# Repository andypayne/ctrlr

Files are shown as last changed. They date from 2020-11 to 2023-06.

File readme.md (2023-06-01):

# CTRLR MIDI Controller

A programmable MIDI Controller

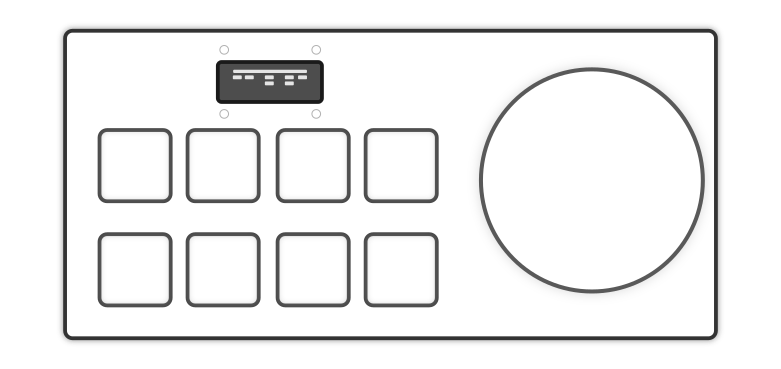
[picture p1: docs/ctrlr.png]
CTRLR


## Hardware

- [Teensy 4.0](https://www.pjrc.com/store/teensy40.html)
- [Adafruit SSD1306 128x32 display](https://www.adafruit.com/product/661)
- 8 pushbuttons (from [Anchor Electronics](https://anchor-electronics.com/))
- A rotary encoder
- 3D-printed enclosure, buttons caps, and rotary wheel

### Enclosure

The [enclosure](/enclosure) was designed with [Solvespace](https://solvespace.com/), a parametric 3D CAD tool. The button pads and dial were designed with [OpenSCAD](http://www.openscad.org/).

#### Top

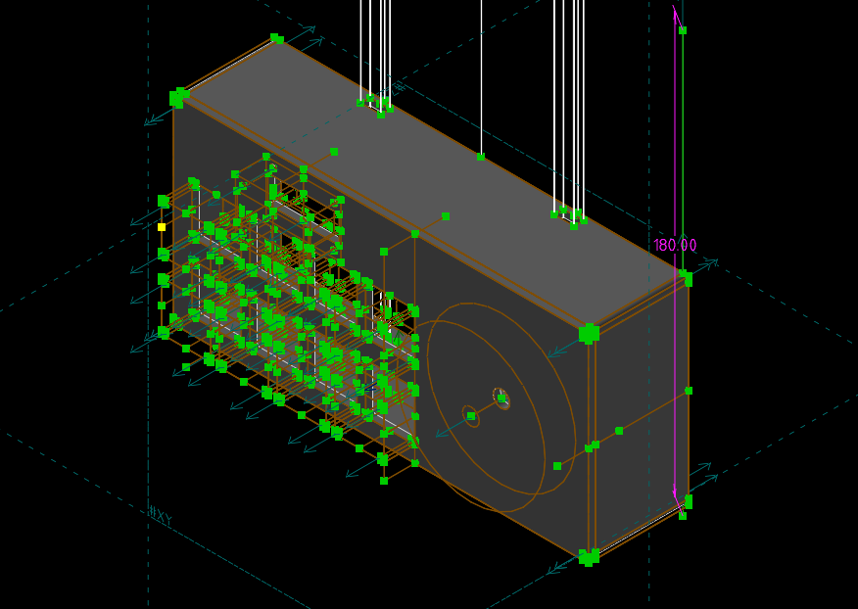
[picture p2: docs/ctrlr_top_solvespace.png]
CTRLR Enclosure Top


#### Bottom

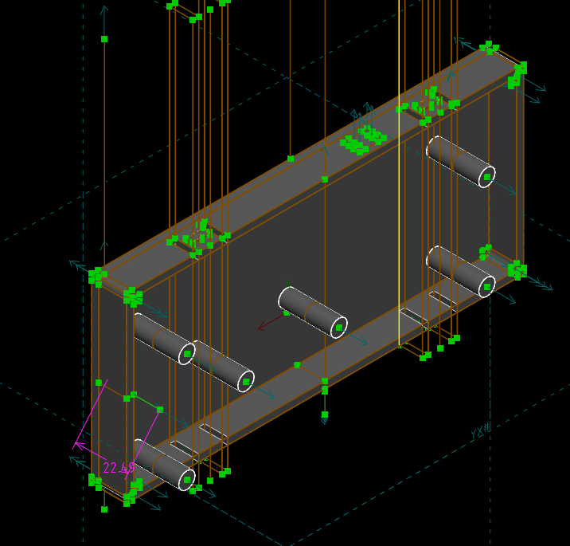
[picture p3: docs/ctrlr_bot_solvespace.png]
CTRLR Enclosure Bottom


## Installation with Arduino

### Arduino

Install [Arduino](https://www.arduino.cc/en/software) 2.0+.

### Teensyduino

Follow [these instructions](https://www.pjrc.com/teensy/td_download.html) to install the Teensyduino add-on. ([board manager url](https://www.pjrc.com/teensy/package_teensy_index.json))

Then to use the Teensy 4.0 board, in the Arduino menu select `Tools -> Board -> Teensy -> Teensy 4.0`.

### Adafruit libraries

To use the SSD1306 display, these libraries need to be installed in Arduino. For newer versions, just search for and install the display type in the Arduino library manager (`"Adafruit SSD1306"` for this project), and the required dependencies (notably Adafruit GFX Library & Adafruit BusIO Library) will be installed with it.

- [Adafruit GFX Graphics Library](https://learn.adafruit.com/adafruit-gfx-graphics-library/overview)
- [Adafruit SSD1306](https://github.com/adafruit/Adafruit_SSD1306)

### Project Dependencies

Clone these repositories:

- [buttoner](https://github.com/andypayne/buttoner)
- [midi_defs](https://github.com/andypayne/midi_defs)

### USB MIDI

To enable [MIDI device](https://www.pjrc.com/teensy/td_midi.html) support for the Teensy, select `Tools -> USB Type -> MIDI` in the Arduino menu. Then the project should build successfully. To upload to a board, select the appropriate port.

## Pure Data integration

Objects for [Pure Data](https://puredata.info/) are located in [/PureData](/PureData).

### ctrlr.pd

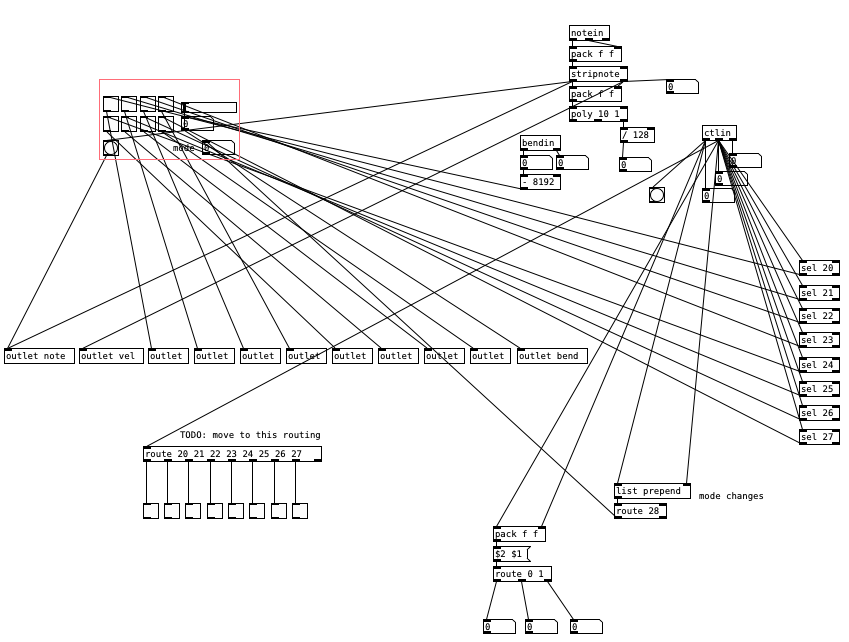
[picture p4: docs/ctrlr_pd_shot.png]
ctrlr.pd


### ctrlr_test.pd

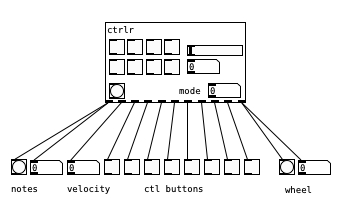
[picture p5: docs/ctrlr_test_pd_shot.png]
ctrlr_test.pd


## Operation Modes

### 16-Step Sequencer

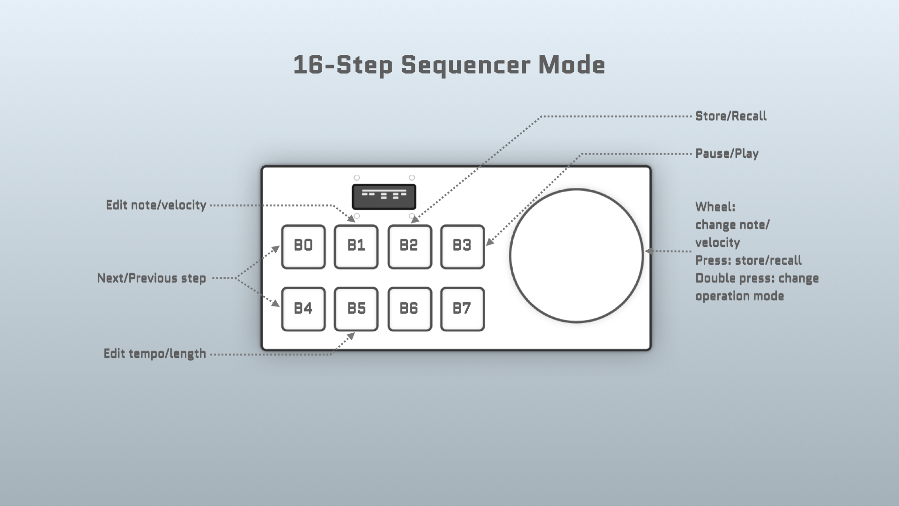
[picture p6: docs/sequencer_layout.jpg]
sequencer mode


## Issues

### Enclosure

The enclosure had several issues, most of which would be fixed in a second revision. I haven't done this yet, partially due to the difficulty and cost of printing another revision.

- _Material_ - The 3D-printed material is a bit too brittle for this application.
- _Height_ - The enclosure is unnecessarily tall, due to my poor planning. I think it gives the device a clunky 70s feel.
- _Support columns_ - I didn't properly attach these to the base in Solvespace, so most of them separated after printing.
- _Button travel_ - The button switches I used have too much travel for this application. I was determined to use these particular switches for some inexplicable reason.
- _Access to reset_ - The access to the reset button requires disassembling the enclosure, which is not ideal when making mistakes while developing code for the device.
- _Piece fit_ - I made an error in Solvespace when designing the fit mechanism for the top and bottom pieces, so I had to use screws to attach the pieces. This makes the device more fragile.
- _USB port_ - I didn't account for the USB port in my enclosure design, so I had to drill/route a hole for it.

### Screen

- _Size_ - The screen size is too small. The positive benefit of this is that it provided a constraint that required some creativity to overcome with some of the modes. It was an interesting challenge to fit the right details on the available screen real estate.
- _Asymmetry_ - I didn't pay close attention to the screen asymmetry when designing the enclosure cutout for it. The screen sits to one side of the cutout.
- _Screen fit_ - I mis-measured the mounting layout for the screen, so the resulting mount on the enclosure is the wrong size, and so the mounted screen causes the enclosure to bow out a little.
- _Screen connectors_ - I didn't properly account for the screen's header pins and connectors header pin connectors when laying out the enclosure, so I had to refit them, and cut out a section of my stripboard to accommodate.

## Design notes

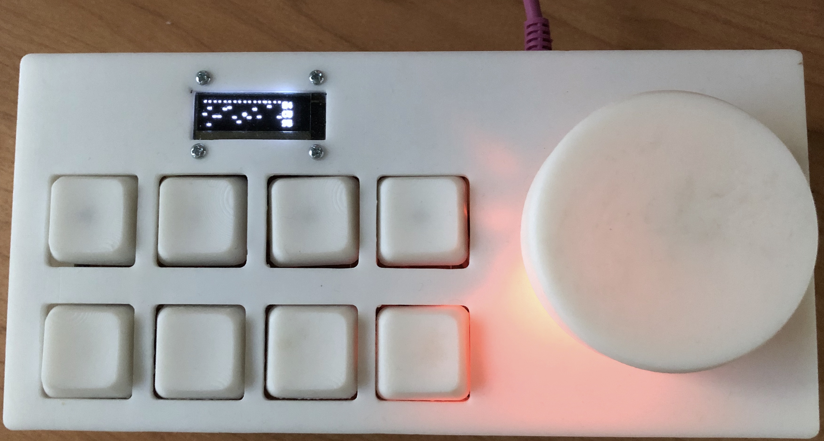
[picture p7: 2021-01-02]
docs/CTRLR_overhead_shot.jpg

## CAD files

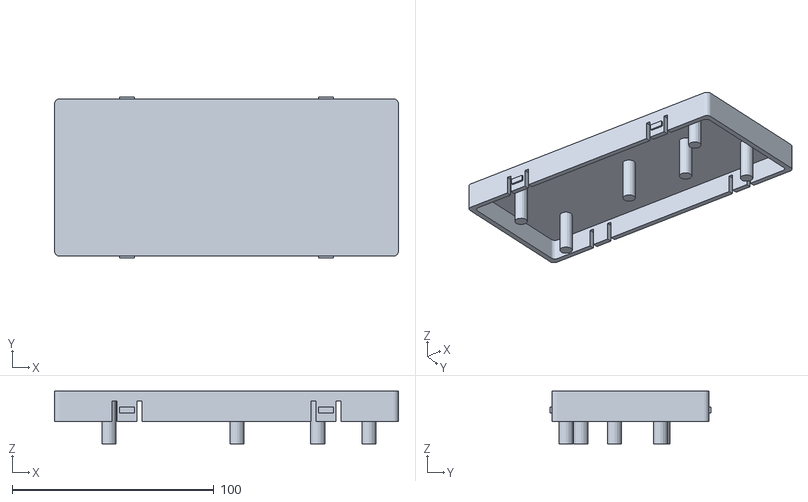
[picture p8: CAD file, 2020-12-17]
enclosure/ctrlr_enclosure_bot.stl
170.5 x 80.0 x 26.2

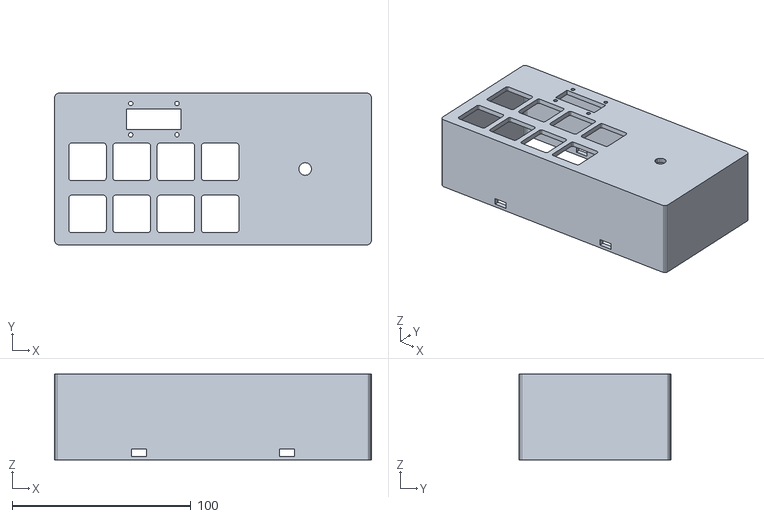
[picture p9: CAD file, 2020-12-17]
enclosure/ctrlr_enclosure_top.stl
177.5 x 85.0 x 48.0

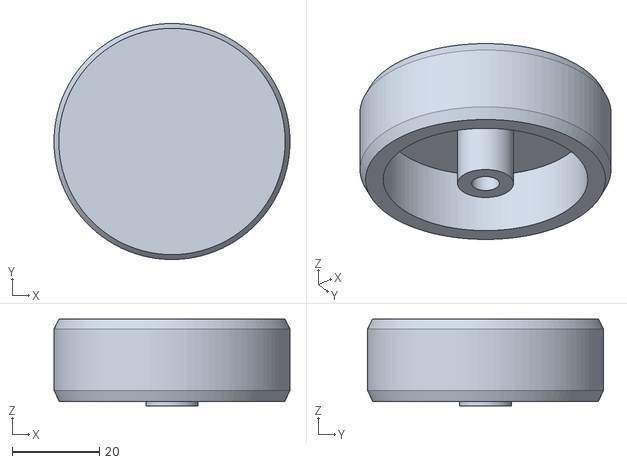
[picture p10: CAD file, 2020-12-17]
enclosure/ctrlr_enclosure_knob.stl
54.0 x 54.0 x 19.8

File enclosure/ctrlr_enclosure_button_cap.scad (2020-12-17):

$fn = 150;

cross_bar_thickness     = 1.13;
cross_height            = 4.52;
// The cross bar is off centered, so I'm making both bar dimensions equal to
// the longest bar to minimize fit issues.
//cross_width             = 3.76;
cross_width             = 4.52;
cross_z_height          = 5.6 + 0.2;
button_base_width       = 15;
button_base_length      = 15;
button_height           = 8;
button_offset           = 3;
button_height_scale     = 0.75;
button_top_neg_radius   = 40;
button_neg_z_pos        = button_height + 0.968 * button_top_neg_radius;

module button_crossbar() {
    color("purple")
    translate([-0.5 * cross_width, -0.5 * cross_bar_thickness, 0])
    cube([cross_width, cross_bar_thickness, cross_z_height]);

    translate([-0.5 * cross_bar_thickness, -0.5 * cross_height, 0])
    cube([cross_bar_thickness, cross_height, cross_z_height]);
}

module button_body() {
color("blue")
translate([0, 0, 0.1])
linear_extrude(height = button_height, center = false, convexity = 20, scale=button_height_scale)
translate([
    -0.5 * button_base_length,
    -0.5 * button_base_width,
    0.5 * button_height])
offset(r=button_offset)
square(size=[button_base_length, button_base_width]);
}

module button_top_neg() {
    translate([0, 0, button_neg_z_pos])
    sphere(r=button_top_neg_radius);
}

translate([21, 0, 0])
difference() {
    button_body();
    button_crossbar();
    button_top_neg();
}

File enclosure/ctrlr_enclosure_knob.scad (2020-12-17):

$fn = 100;

// All in mm

threaded_shaft_diam    = 7.1;  // Not used, too low
threadless_shaft_diam  = 6.0;
notch_pos_thickness    = 4.8;
notched_shaft_height   = 10.5;
notchless_shaft_height = 3.3;
top_thickness          = 5.0;
outer_cyl_height       = notched_shaft_height + notchless_shaft_height + top_thickness;
outer_cyl_diam         = 54.0;
shaft_hole_diam        = 6.0;
notch_neg_width        = threadless_shaft_diam - notch_pos_thickness;

neg_inner_cyl_height = outer_cyl_height;
neg_inner_cyl_diam   = outer_cyl_diam - 10.0;
inner_post_overhang  = 1.0;
inner_post_height    = outer_cyl_height + inner_post_overhang;
inner_post_diam      = 12.0;
shaft_hole_height    = inner_post_height;

// Notch in the shaft negative
color("red")
translate([0.5 * threadless_shaft_diam - notch_neg_width, -0.5 * threadless_shaft_diam, notchless_shaft_height])
cube([notch_neg_width, threadless_shaft_diam, notched_shaft_height]);

intersection() {
    intersection() {
        // Negative cone for chamfer top
        translate([0, 0, -50]) cylinder(h=120, d1=120, d2=1);
        difference() {
            cylinder(h=outer_cyl_height, d=outer_cyl_diam);
            translate([0, 0, -top_thickness])
                cylinder(h=neg_inner_cyl_height, d=neg_inner_cyl_diam);
        }
    }

    // Negative cone for chamfer bottom
    rotate([180, 0, 0]) translate([0, 0, -69]) cylinder(h=120, d1=120, d2=1);
}


difference() {
    translate([0, 0, -inner_post_overhang])
        cylinder(h=inner_post_height, d=inner_post_diam);
    translate([0, 0, -inner_post_overhang - 3.0])
        cylinder(h=shaft_hole_height, d=shaft_hole_diam);
}

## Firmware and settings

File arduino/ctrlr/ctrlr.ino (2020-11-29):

#include "ctrlr.h"

//
// Set Tools --> USB Type --> MIDI
//

#define MIDI_CHANNEL 1

#define IN0_BTN     21
#define IN1_BTN     19
#define IN2_BTN     17
#define IN3_BTN     15
#define IN4_BTN     20
#define IN5_BTN     18
#define IN6_BTN     16
#define IN7_BTN     22
#define IN_RENC_SW  7
#define IN_RENC_DT  5
#define IN_RENC_CLK 6

Ctrlr ctrlr(
  MIDI_CHANNEL,
  IN0_BTN,
  IN1_BTN,
  IN2_BTN,
  IN3_BTN,
  IN4_BTN,
  IN5_BTN,
  IN6_BTN,
  IN7_BTN,
  IN_RENC_SW,
  IN_RENC_DT,
  IN_RENC_CLK
);

void setup() {
  Serial.begin(9600);
  randomSeed(analogRead(0));
  ctrlr.setup();
}

void loop() {
  ctrlr.update();
}

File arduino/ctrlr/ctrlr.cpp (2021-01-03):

#include "ctrlr.h"

Ctrlr::Ctrlr(
  int midiChannel,
  int in0Pin,
  int in1Pin,
  int in2Pin,
  int in3Pin,
  int in4Pin,
  int in5Pin,
  int in6Pin,
  int in7Pin,
  int inRencSwitch,
  int inRencDT,
  int inRencCLK) :
    _modeChanging(false),
    _modeSel(mnote),
    _sw_millis(SW_MILLIS),
    _rencBtnr(HIGH, LOW, HIGH, SW_MILLIS, SW_DBL_MILLIS),
    _b0Btnr(HIGH, LOW, HIGH, SW_MILLIS, SW_DBL_MILLIS),
    _b1Btnr(HIGH, LOW, HIGH, SW_MILLIS, SW_DBL_MILLIS),
    _b2Btnr(HIGH, LOW, HIGH, SW_MILLIS, SW_DBL_MILLIS),
    _b3Btnr(HIGH, LOW, HIGH, SW_MILLIS, SW_DBL_MILLIS),
    _b4Btnr(HIGH, LOW, HIGH, SW_MILLIS, SW_DBL_MILLIS),
    _b5Btnr(HIGH, LOW, HIGH, SW_MILLIS, SW_DBL_MILLIS),
    _b6Btnr(HIGH, LOW, HIGH, SW_MILLIS, SW_DBL_MILLIS),
    _b7Btnr(HIGH, LOW, HIGH, SW_MILLIS, SW_DBL_MILLIS),
    _bb0({ defBtnMode, 60, maj_7(60), 20, MidiDefs::MIDI_HIGH, 0, Metro(BPM_TO_MILLIS(DEF_REP_BPM)) }),  // Cmaj
    _bb1({ defBtnMode, 61, min_7(62), 21, MidiDefs::MIDI_HIGH, 0, Metro(BPM_TO_MILLIS(DEF_REP_BPM)) }),  // Dmin
    _bb2({ defBtnMode, 62, min_7(64), 22, MidiDefs::MIDI_HIGH, 0, Metro(BPM_TO_MILLIS(DEF_REP_BPM)) }),  // Emin
    _bb3({ defBtnMode, 63, maj_7(65), 23, MidiDefs::MIDI_HIGH, 0, Metro(BPM_TO_MILLIS(DEF_REP_BPM)) }),  // Fmaj
    _bb4({ defBtnMode, 64, dom_7(67), 24, MidiDefs::MIDI_HIGH, 0, Metro(BPM_TO_MILLIS(DEF_REP_BPM)) }),  // Gmaj
    _bb5({ defBtnMode, 65, min_7(69), 25, MidiDefs::MIDI_HIGH, 0, Metro(BPM_TO_MILLIS(DEF_REP_BPM)) }),  // Amin
    _bb6({ defBtnMode, 66, dim_7(71), 26, MidiDefs::MIDI_HIGH, 0, Metro(BPM_TO_MILLIS(DEF_REP_BPM)) }),  // Bmin7b5
    _bb7({ defBtnMode, 67, maj_7(72), 27, MidiDefs::MIDI_HIGH, 0, Metro(BPM_TO_MILLIS(DEF_REP_BPM)) }),  // Cmaj
    _btn0_tog(HIGH),
    _btn1_tog(HIGH),
    _btn2_tog(HIGH),
    _btn3_tog(HIGH),
    _btn4_tog(HIGH),
    _btn5_tog(HIGH),
    _btn6_tog(HIGH),
    _btn7_tog(HIGH),
    _renc(inRencDT, inRencCLK),
    _display(
      SCREEN_WIDTH,
      SCREEN_HEIGHT,
      OLED_MOSI,
      OLED_CLK,
      OLED_DC,
      OLED_RESET,
      OLED_CS),
    _metroBpm(METRO_BPM),
    _metro(BPM_TO_MILLIS(METRO_BPM)),
    _seqNote(0),
    _delayOn(false),
    _chordsOn(false),
    //_seqSteps{ {0, 0}, {0, 0}, {0, 0}, {0, 0}, {0, 0}, {0, 0}, {0, 0}, {0, 0}, {0, 0}, {0, 0}, {0, 0}, {0, 0}, {0, 0}, {0, 0}, {0, 0}, {0, 0} },
    //_seqSteps{ {60, 64}, {64, 80}, {62, 0}, {60, 10}, {66, 80}, {64, 0}, {66, 10}, {62, 80}, {60, 0}, {64, 10}, {68, 80}, {62, 0}, {62, 10}, {64, 0}, {60, 64}, {70, 90} },
    //_seqSteps{ {60, 0}, {60, 0}, {60, 0}, {60, 0}, {60, 0}, {60, 0}, {60, 0}, {60, 0}, {60, 0}, {60, 0}, {60, 0}, {60, 0}, {60, 0}, {60, 0}, {60, 0}, {60, 0} },
    _seqSteps{ {60, 95}, {60, 95}, {60, 95}, {60, 95}, {60, 95}, {60, 95}, {60, 95}, {60, 95}, {60, 95}, {60, 95}, {60, 95}, {60, 95}, {60, 95}, {60, 95}, {60, 95}, {60, 95} },
    _seqEditStep(0),
    _seqPlaying(true),
    _numSeq2Steps(NUM_SEQ2_STEPS),
    _editMode(senote)
{
  _midiChannel = midiChannel;
  _in0Pin = in0Pin;
  _in1Pin = in1Pin;
  _in2Pin = in2Pin;
  _in3Pin = in3Pin;
  _in4Pin = in4Pin;
  _in5Pin = in5Pin;
  _in6Pin = in6Pin;
  _in7Pin = in7Pin;
  _inRencSwitch = inRencSwitch;
  _inRencDT = inRencDT;
  _inRencCLK = inRencCLK;

  pinMode(_inRencSwitch, INPUT);
  pinMode(_in0Pin, INPUT_PULLUP);
  pinMode(_in1Pin, INPUT_PULLUP);
  pinMode(_in2Pin, INPUT_PULLUP);
  pinMode(_in3Pin, INPUT_PULLUP);
  pinMode(_in4Pin, INPUT_PULLUP);
  pinMode(_in5Pin, INPUT_PULLUP);
  pinMode(_in6Pin, INPUT_PULLUP);
  pinMode(_in7Pin, INPUT_PULLUP);

  _pin0_val = HIGH;
  _pin1_val = HIGH;
  _pin2_val = HIGH;
  _pin3_val = HIGH;
  _pin4_val = HIGH;
  _pin5_val = HIGH;
  _pin6_val = HIGH;
  _pin7_val = HIGH;
  _renc_sw_val = 0;
  _renc_val = 0;
  _renc_pitch_val = 0;
  _renc_sw_time = 0;
  _btn0_time = 0;
  _btn1_time = 0;
  _btn2_time = 0;
  _btn3_time = 0;
  _btn4_time = 0;
  _btn5_time = 0;
  _btn6_time = 0;
  _btn7_time = 0;

  _seqStep = 0;
  _btn0_seq = 0;
  _btn1_seq = 0;
  _btn2_seq = 0;
  _btn3_seq = 0;
  _btn4_seq = 0;
  _btn5_seq = 0;
  _btn6_seq = 0;
  _btn7_seq = 0;
}

void Ctrlr::setup() {
#if defined SSD1306_128_32
  Serial.print(F("SSD1306_128_32 is defined"));
#endif

  delay(500);

  _rencBtnr.setup();
  _b0Btnr.setup();
  _b1Btnr.setup();
  _b2Btnr.setup();
  _b3Btnr.setup();
  _b4Btnr.setup();
  _b5Btnr.setup();
  _b6Btnr.setup();
  _b7Btnr.setup();

  // SSD1306_SWITCHCAPVCC = generate display voltage from 3.3V internally
  if(!_display.begin(SSD1306_SWITCHCAPVCC)) {
    Serial.println(F("SSD1306 allocation failed"));
    for(;;);
  }

  _display.clearDisplay();
  _display.display();
  displayBootScreen();
}

void Ctrlr::displayBootScreen() {
  _display.clearDisplay();
  for(int16_t i = _display.height() / 2 - 1; i >= 0; i -= 2) {
    drawBootRect(i, i, 30);
    _display.clearDisplay();
  }
  for(int16_t i = 0; i < _display.height() / 2; i += 2) {
    drawBootRect(i, i, 30);
    _display.clearDisplay();
  }
  for(int16_t i = _display.height() / 2 - 1; i >= 0; i -= 2) {
    drawBootRect(i, i, 30);
    _display.clearDisplay();
  }
  for(int16_t i = 0; i < _display.height() / 2; i += 2) {
    drawBootRect(i, i, 30);
    _display.clearDisplay();
  }
  for(int16_t i = _display.height() / 2 - 1; i >= 0; i -= 2) {
    drawBootRect(i, i, 30);
    if (i > 1) {
      _display.clearDisplay();
      _display.display();
    }
  }
  _display.setTextSize(2);
  _display.setTextColor(SSD1306_WHITE);
  _display.setCursor(36, 9);
  _display.cp437(true);
  _display.println(F("CTRLR"));
  _display.display();
  delay(750);
  _display.clearDisplay();
  for(int16_t i = 0; i < _display.height() / 2; i += 2) {
    drawBootRect(i, i, 16);
    _display.clearDisplay();
  }
  _display.clearDisplay();
  _display.display();
  delay(200);
}

void Ctrlr::drawBootRect(const int x, const int y, const int delayMs) {
  _display.drawRect(x, y, _display.width() - 2 * x, _display.height() - 2 * y, SSD1306_WHITE);
  _display.display();
  delay(delayMs);
}
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

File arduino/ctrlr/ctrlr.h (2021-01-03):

#ifndef CTRLR_H
#define CTRLR_H

#include <SPI.h>
#include <Wire.h>
#include <EEPROM.h>

// Adafruit SSD1306
// https://github.com/adafruit/Adafruit_SSD1306
#include <Adafruit_GFX.h>
#include <Adafruit_SSD1306.h>

// PJRC Encoder Library
// https://www.pjrc.com/teensy/td_libs_Encoder.html
#include <Encoder.h>

// https://playground.arduino.cc/Code/Metro/
#include <Metro.h>

// https://github.com/andypayne/midi_defs
#include "../../midi_defs/midi_defs.h"
// https://github.com/andypayne/buttoner
#include "../../buttoner/buttoner.h"

// SSD1306 128x32 panel
#define SCREEN_WIDTH 128
#define SCREEN_HEIGHT 32

// Declaration for SSD1306 display connected using software SPI (default case):
#define OLED_MOSI   9
#define OLED_CLK   10
#define OLED_DC    11
#define OLED_CS    12
#define OLED_RESET 13

#define SW_MILLIS      450
#define SW_DBL_MILLIS  200

#define VEL_NOTE_ON   99
#define VEL_NOTE_OFF  0

#define MODE_CHG_CTL_NUM  28

#define BPM_TO_MILLIS(bpm) ((60.0 / bpm) * 1000.0)
#define METRO_BPM 120

#define NUM_SEQ_STEPS  8
#define NUM_SEQ2_STEPS  16

int cycleBtnSeq(const int btnSeq);


class Ctrlr
{
  public:
    enum btnMode {
      mnote,
      mcchg,
      mcchg2,  // Send MIDI_LOW on release
      mcchg3,  // Repeat mode
      mnseq2,  // Sequencer 2
      mnseq,   // Note sequencer mode
    };
    const int NUM_BTN_MODES = 5;

    // Damping increment for the rotary encoder mode change
    const int DAMP_INCR = 5;

    // Delay repeat max
    const int MAX_REP_COUNT = 16;
    // Default delay BPM
    const int DEF_REP_BPM = 500;

    // EEPROM addresses
    const int EADDR_TEMPO = 0;
    const int EADDR_LEN = 1;
    const int EADDR_SEQ = 2;

    btnMode defBtnMode = mnseq2;

    struct btnBehavior {
      btnMode mode;
      int noteVal;
      int chordVal[3];
      int ctlNum;
      int ctlVal;
      int repCount;
      Metro repMetro;
    };

    struct noteSpec {
      int note;
      int vel;
    };

    enum seqEditMode {
      senote,
      sevel,
      setempo,
      selen,
      sesto,
      serec
    };

    Ctrlr(
      int midiChannel,
      int in0Pin,
      int in1Pin,
      int in2Pin,
      int in3Pin,
      int in4Pin,
      int in5Pin,
      int in6Pin,
      int in7Pin,
      int inRencSwitch,
      int inRencDT,
      int inRencClk
    );

    void setup();
    void update();
    void displayBootScreen();
    void drawBootRect(const int x, const int y, const int delayMs);
    void drawRencIndicator(const float indX, const float indY, const float rencX, const float rencY);
    void displayControllerView();
    void printBtnStatus(const char *pre, Buttoner& bBtnr);
    void displayDebugView();
    void displaySeq2();
    void displayCurrentMode();
    void displayButtonStatus(const int pinVal, const int btnTog, const int btnX, const int btnY, const float btnSz, const float btnRad);
    void processBtn(btnBehavior& bb, Buttoner& bBtnr, int& pinVal, int& btnTog, int& btnSeq, long& btnTime);
    const btnMode relativeMode(const btnMode& mode, const int relVal);
    void doRepeats(btnBehavior& bb);
    void storeSeq();
    void recallSeq();

  private:
    // the MIDI channel number to send messages
    int _midiChannel;

    int _in0Pin;
    int _in1Pin;
    int _in2Pin;
    int _in3Pin;
    int _in4Pin;
    int _in5Pin;
    int _in6Pin;
    int _in7Pin;
    int _inRencSwitch;
    int _inRencDT;
    int _inRencCLK;

    int _pin0_val;
    int _pin1_val;
    int _pin2_val;
    int _pin3_val;
    int _pin4_val;
    int _pin5_val;
    int _pin6_val;
    int _pin7_val;
    int _renc_sw_val;
    long _renc_val;
    long _renc_pitch_val;
    bool _modeChanging;
    btnMode _modeSel;
    long _renc_sw_time;
    long _sw_millis;

    Buttoner _rencBtnr;
    Buttoner _b0Btnr;
    Buttoner _b1Btnr;
    Buttoner _b2Btnr;
    Buttoner _b3Btnr;
    Buttoner _b4Btnr;
    Buttoner _b5Btnr;
    Buttoner _b6Btnr;
    Buttoner _b7Btnr;

    btnBehavior _bb0;
    btnBehavior _bb1;
    btnBehavior _bb2;
    btnBehavior _bb3;
    btnBehavior _bb4;
    btnBehavior _bb5;
    btnBehavior _bb6;
    btnBehavior _bb7;
    int _btn0_tog;
    int _btn1_tog;
    int _btn2_tog;
    int _btn3_tog;
    int _btn4_tog;
    int _btn5_tog;
    int _btn6_tog;
    int _btn7_tog;
    long _btn0_time;
    long _btn1_time;
    long _btn2_time;
    long _btn3_time;
    long _btn4_time;
    long _btn5_time;
    long _btn6_time;
    long _btn7_time;
    Encoder _renc;
    Adafruit_SSD1306 _display;
    int _metroBpm;
    Metro _metro;
    int _seqStep;
    int _btn0_seq;
    int _btn1_seq;
    int _btn2_seq;
    int _btn3_seq;
    int _btn4_seq;
    int _btn5_seq;
    int _btn6_seq;
    int _btn7_seq;
    int _seqNote;
    bool _delayOn;
    bool _chordsOn;
    noteSpec _seqSteps[NUM_SEQ2_STEPS];
    int _seqEditStep;
    bool _seqPlaying;
    int _numSeq2Steps;
    seqEditMode _editMode;
};

#endif

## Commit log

2020-10-15 Move button handlers to callbacks
2020-10-23 Controller display view. Reorder encoder read/MIDI send.
2020-10-23 Add note mode and control change mode for buttons. Add mode switching and mode button momentary debouncing.
2020-10-23 Display tweaks. Move btnBehavior initialization to the constructor. Define a default mode for all buttons.
2020-10-27 Rework to send MIDI low or nothing on release
    [ctrlr.cpp]
2020-10-29 Display button state as toggles in repeat control mode. Display the tempo in repeat control mode.
2020-11-05 Add more velocity levels to the note sequencer.
2020-11-08 Added a new library for managing buttons/switches, buttoner. Used buttoner on the rotary encoder for now. Moved the mode change to double-press. Reduced the splash screen time.
2020-11-09 Refactored around buttoner in preparation for leveraging button hold events.
2020-11-12 Use the single press event for note sequencing mode. Add a method to display the button status for debugging.
2020-12-16 enclosure diagram
2020-12-17 Make arduino happy
2020-12-17 Files for 3D-printed enclosure
    [ctrlr_enclosure_bot.stl, ctrlr_enclosure_button_cap.scad, ctrlr_enclosure_knob.scad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]
2021-01-10 Enclosure images from Solvespace
2021-01-10 Enclosure Solvespace images
2021-01-10 Info on the enclosure
